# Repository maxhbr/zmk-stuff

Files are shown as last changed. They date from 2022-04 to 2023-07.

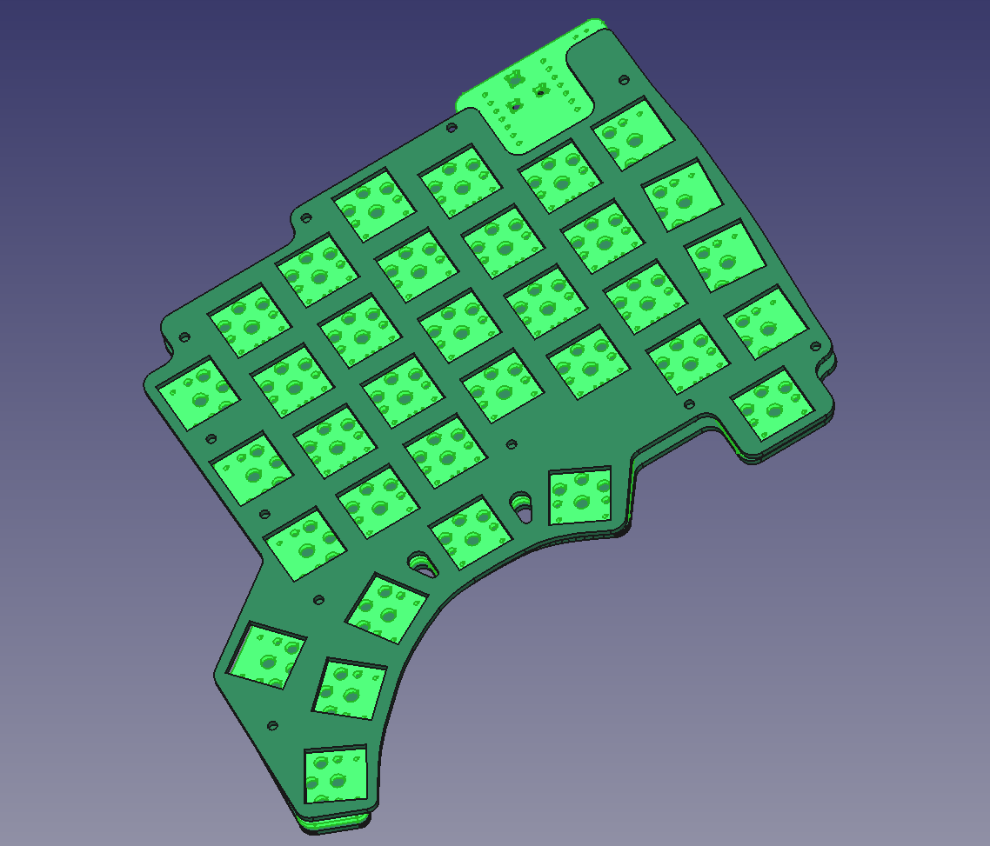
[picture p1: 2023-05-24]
mykeeb/rev7/mykeeb_v7a3/mykeeb_v7a3.png

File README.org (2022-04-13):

* zmk-stuff

** Keyboards
*** REDOX
my current daily driver
*** Kyria
Not sufficient amount of keys, not OSS
*** NYX
I am not happy with the thumb cluster, maybe it is good for gaming.
*** planned / parts exist / untested
**** ErgoDash
**** CRKBD

** Cases:
the cases are found in https://github.com/maxhbr/things/tree/main/keyboards

* TODOs:
** TODO clarify license situation
** TODO bulid configurations only on change?
** TODO design the perfect keyboard

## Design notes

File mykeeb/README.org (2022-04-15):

* mykeeb
** Why not an existing keeb
- [[https://github.com/mattdibi/redox-keyboard][REDOX]]
  - is very close
    - no HotSwap in the open source variant
- [[https://github.com/tadfisher/nyx-kb/][NYX]]
  - not happy with the thumb cluster
- Kyria
  - not OSS
  - to less keys
- [[https://github.com/omkbd/ErgoDash][ErgoDash]]
  - similar to REDOX
  - thumb cluster is forced to use one 2U
- [[https://github.com/jpconstantineau/ErgoTravel][ErgoTravel]]
- Zordiak is not OSS
- [[https://github.com/Pekaso/fortitude60][fortitude60]]
  - MCU is *Beetle USB 32u4* -> not supported by ZMK
- [[https://github.com/KarlK90/yaemk-split-kb][YAEMK]]
  - not supported by ZMK
- [[https://github.com/vlkv/avalanche][The Avalanche keyboard]]
  - tbd.

Other interesting Keyboards are Lily58, Lotus58, Sofle,

** Goals
- it *must* be fully OSS
  - especially also PCB and case
- it *must* support ZMK
  - it *could* have QMK support
- it *must* support 3D printed case and switch plate
  - it *should* have tenting support
- it *should* be split
- it *must* have columnar staggered layout
  - similar to Kyria or REDOX
    - Kyria aggressiveness is great!
- it *should* have _a lot_ of keys:
  - got used to 35 keys per side. Maybe 30 could also be sufficient.
  - it *must* have a thumb cluster
    - maybe a combination of REDOX-style and NYX-style
  - it *must* have 6 cols
    - it *should* have 7 cols, i.e. an additional center column
  - it *should* have a Number row
  - it *could* have arrow keys
  - it *does not need* to have encoder support
- it *could* have 1.5u keys for parts of the thumb cluster
- it *should* have MX style switches
  - it *could* also have Choc compatibility
    - maybe specifically for the thumb cluster?
- it *should* have HotSwap
  - preferred via Kailh sockets
- MCU *should* be mounted visible, and not on the back side
  - MCU *could* have two sockets to choose orientation per side
    - I like them chip side up
  - maybe similar to NYX, Kyria or crkbd
  - MCU *should* use a standard interconnect like Pro Micro
- it *should* have PCB support for a switch and battery connections
- it *could* expose i2c for trackball support
- it *could* have RGB-LED for feedback regarding activated layers or modifier
  - could also be done via display
  - could also be done via the trackpoint led
  - it *does not need* any further LED stuff

** How to start?
- base on something
  - REDOX
    - no HotSwap
  - ErgoDash
    - one less thumb key
  - NYX
    - has MX+Chock footprints, but does not fir 5pin MX
    - uses Horizon EDA
- from scratch
  - https://github.com/ruiqimao/keyboard-pcb-guide
  - which MCU
    - nRF52840
      - Nice!Nano
        - can easily do >=42 switches per side (41 on reviung41), using 6+7 GPIO pins
      - nRF52830 Dongle
        - 15 GPIOs
        - no LiPo support
      - Seeed XIAO BLE
        - has 11 GPIO pins
          - max 30=5*6 switches?
          - hummingbird has 30 switches
    - esp32

* Links:
- https://github.com/diimdeep/awesome-split-keyboards

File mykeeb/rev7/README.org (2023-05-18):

#+title: Readme

* Building a Redox Style Split with xiaos + Shift Registers

similar to https://github.com/maxhbr/redox-meets-dao-choc-ble, but with a different set of electronics.

*The shift registers are dropped for now, to iterate faster*

** The Idea:
*** Take the electronics from revxlp / uninarf
- Maybe with potential for (partial) JLC PCBA assembly
- using the xiao footprint from the TOTEM
*** Take the Rough layout from Redox
*** Adopt to the pinky stagger from the Kyria

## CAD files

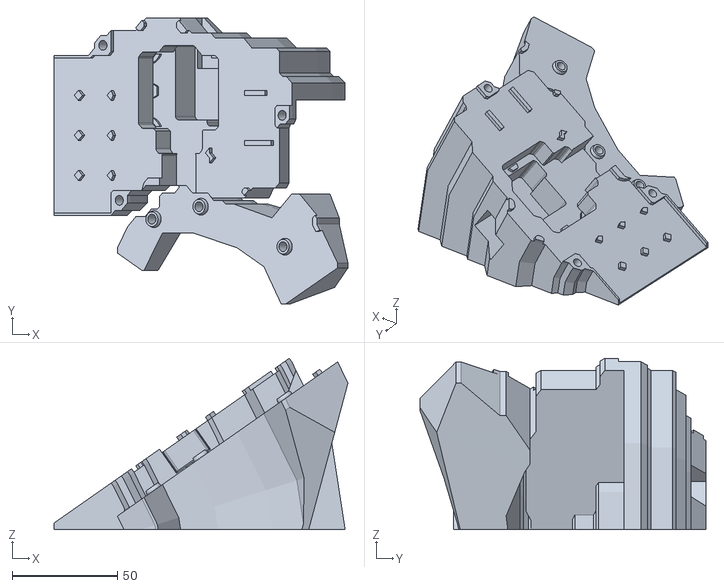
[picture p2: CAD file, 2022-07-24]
mykeeb/rev4c/case/mykeeb-wedge.stl
140.0 x 136.3 x 81.6

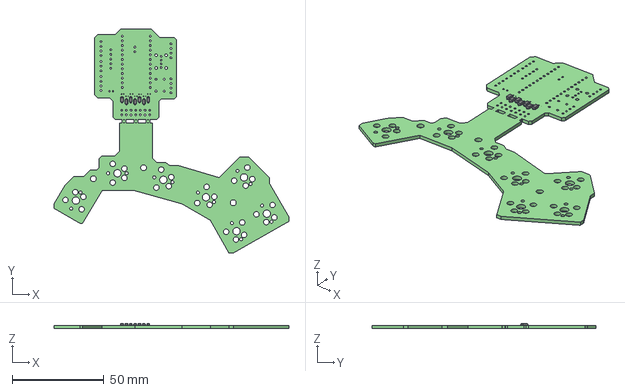
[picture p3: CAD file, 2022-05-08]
mykeeb/rev4c/mykeeb-adapter/mykeeb-adapter.step
128.0 x 122.0 x 2.75 mm
mykeeb-adapter PCB

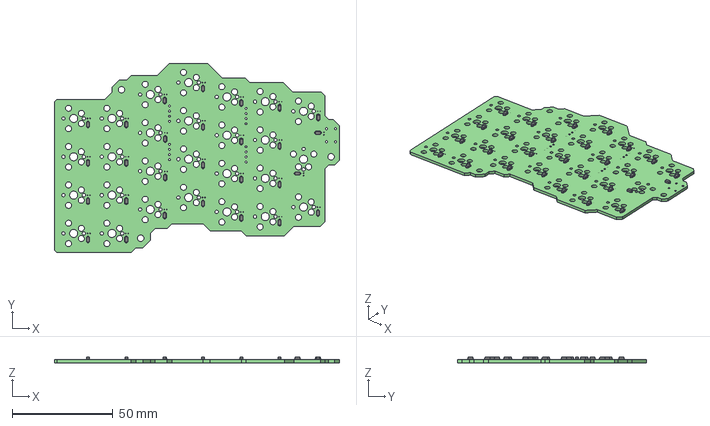
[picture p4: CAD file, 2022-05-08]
mykeeb/rev4c/mykeeb/mykeeb.step
141.7 x 94.1 x 2.75 mm
mykeeb PCB

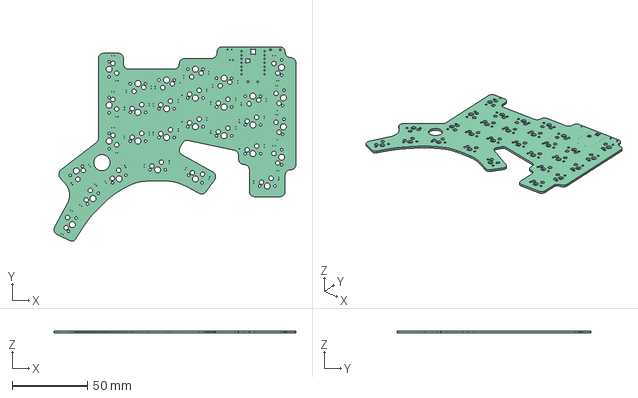
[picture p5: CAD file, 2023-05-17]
mykeeb/rev7/mykeeb_v7a2/mykeeb_v7a2_base/mykeep_v7a2_2023-05-16.FCStd
160.4 x 128.9 x 1.60 mm

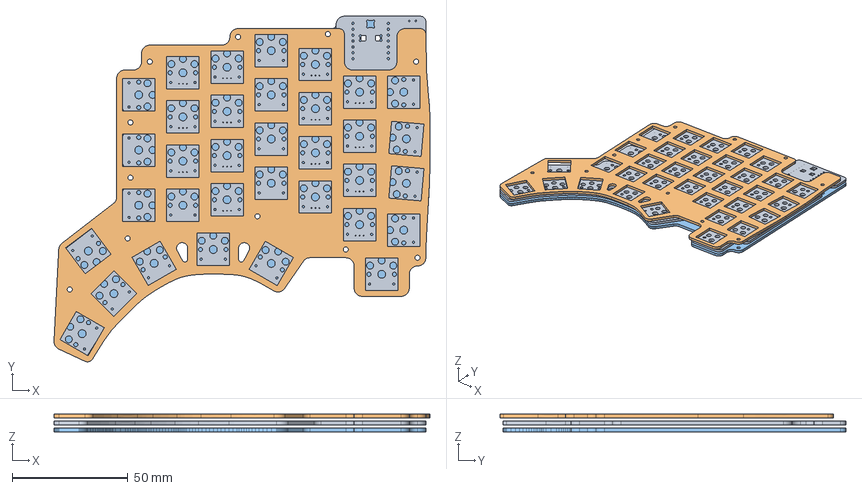
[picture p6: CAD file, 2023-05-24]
mykeeb/rev7/mykeeb_v7a3/mykeeb_v7a3.FCStd
162.2 x 149.1 x 7.60 mm
Pcb_73e4
Pcb_1d9e
Pcb_ed69

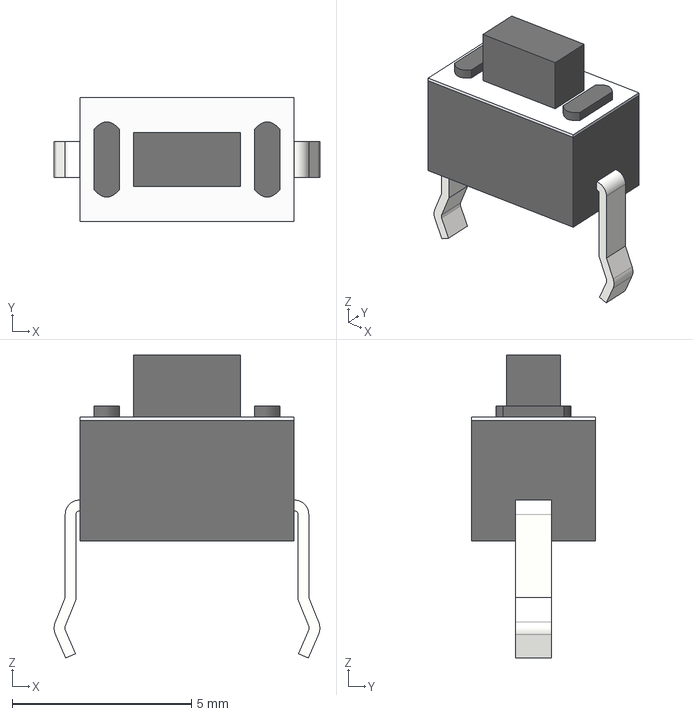
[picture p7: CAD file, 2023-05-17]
mykeeb/rev7/mykeeb_v7a5/pretty/3d_shapes/tact-switch.step
7.42 x 3.46 x 8.46 mm

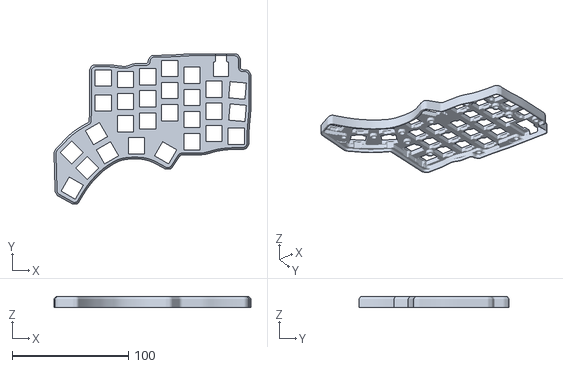
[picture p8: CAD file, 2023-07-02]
mykeeb/rev7/mykeeb_v7a5/stls/mykeeb_v7a5.no-lipo_case.right.stl
169.5 x 129.2 x 9.30

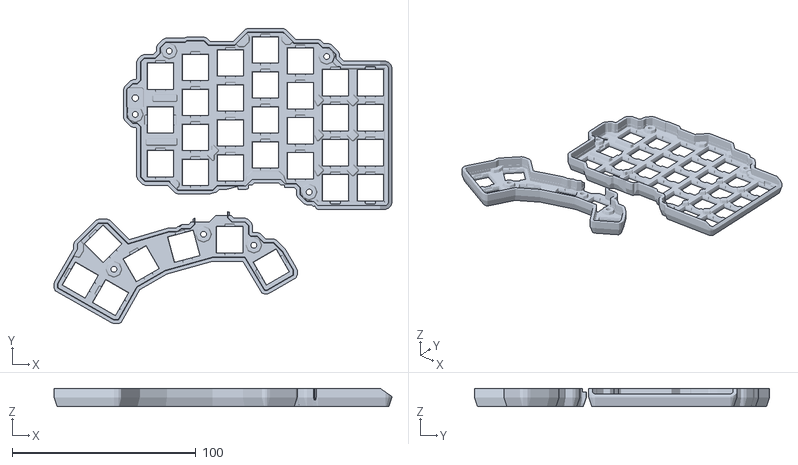
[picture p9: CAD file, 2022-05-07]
mykeeb/rev4c/case/mykeeb-lids.stl
184.0 x 160.8 x 10.0

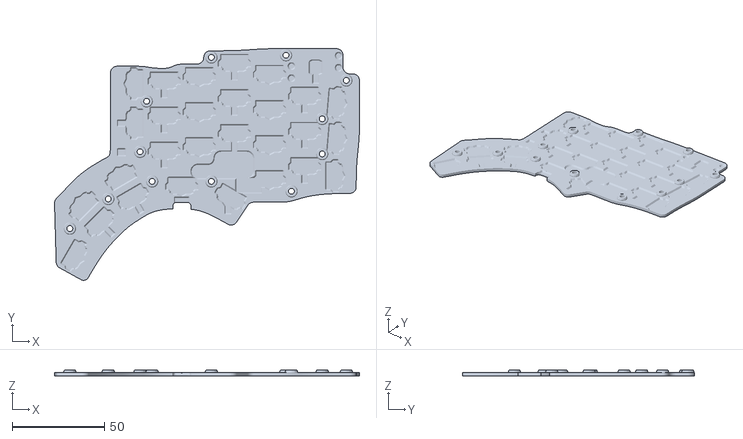
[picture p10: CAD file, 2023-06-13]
mykeeb/rev7/mykeeb_v7a5/stls/mykeeb_v7a5.base.right.stl
165.5 x 125.7 x 3.50

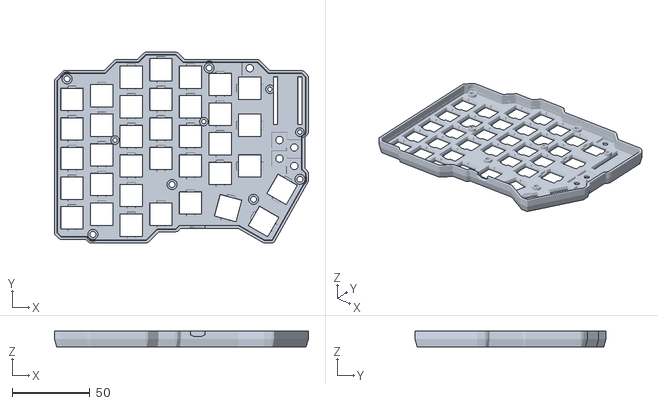
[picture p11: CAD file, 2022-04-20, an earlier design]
mykeeb/rev1/case/mykeeb.stl
163.3 x 123.0 x 10.0

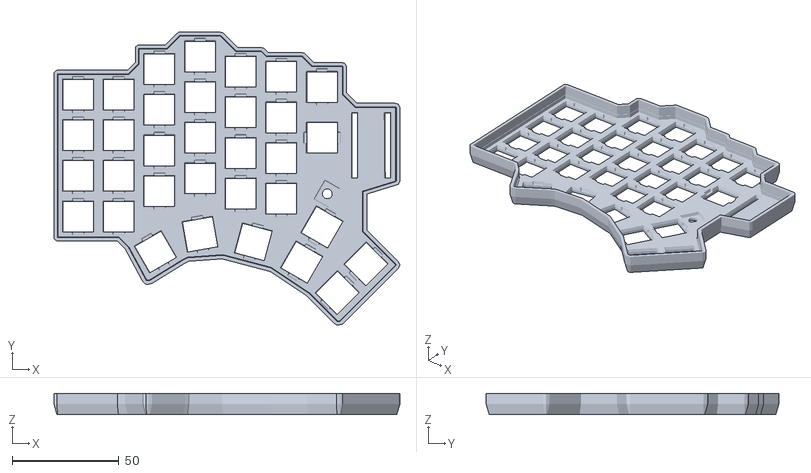
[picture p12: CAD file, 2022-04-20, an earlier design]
mykeeb/rev3/case/mykeeb.stl
162.2 x 137.2 x 10.0

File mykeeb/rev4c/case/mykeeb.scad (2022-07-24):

task=""; // ["","lids","wedge"]

angle=35;
lowerDrop=[0,0,-1.6-11];
lowerOffset=[-0.0005,-43.357,0];


// ############################################################################
// ## lib #####################################################################
// ############################################################################

module limitCube() {
    translate([0,0,-2])
        rotate([0,angle,0])
        translate([-20,-50,0])
        cube([200,150,100]);
}

module tent() {
    t=[-10,0,0];
    a=-35;
    translate(-t)
        rotate([0,a,0])
        translate(t)
        children();
}

module edge(h=3, top=true) {
    linear_extrude(height = h, convexity = 10)
        if (top) {
            import (file = "../mykeeb/mykeeb-Edge_Cuts.svg");
        } else {
            translate(lowerOffset)
                import (file = "../mykeeb-adapter/mykeeb-adapter-Edge_Cuts.svg");
        };
}

module screwHoles(h=10, top=true) {
    minkowski() {
        intersection() {
            linear_extrude(height = h, convexity = 10)
                if (top) {
                    import (file = "../mykeeb/mykeeb-Nutzer_1.svg");
                } else {
                    translate(lowerOffset)
                        import (file = "../mykeeb-adapter/mykeeb-adapter-Nutzer_1.svg");
                }
            edge(h=h,top=top);
        }
        children();
    }
}

module keyCutout(top=true) {
    translate([0,0,-5]) {
        minkowski() {
            intersection() {
                union() {
                    linear_extrude(height = 8.5, convexity = 10)
                        if (top) {
                            import (file = "../mykeeb/mykeeb-Nutzer_2.svg");
                            import (file = "../mykeeb/mykeeb-Nutzer_3.svg");
                        } else {
                            translate(lowerOffset) {
                                import (file = "../mykeeb-adapter/mykeeb-adapter-Nutzer_2.svg");
                                import (file = "../mykeeb-adapter/mykeeb-adapter-Nutzer_3.svg");
                            }
                        };
                }
                edge(h=8.5,top=top);
            }
            if (top) {
                intersection() {
                    linear_extrude(height = 9.2, convexity = 10)
                        import (file = "../mykeeb/mykeeb-Nutzer_5.svg");
                    edge(h=9.2,top=true);
                }
            }
            translate([0,0,-1.5]) cylinder(d1=1,d2=0,h=1.5,$fn=8);
        }
        intersection() {
            linear_extrude(height = 10, convexity = 10)
                if (top) {
                    import (file = "../mykeeb/mykeeb-Nutzer_2.svg");
                } else {
                    translate(lowerOffset)
                        import (file = "../mykeeb-adapter/mykeeb-adapter-Nutzer_2.svg");
                };
            edge(h=10, top=top);
        }
    }
}

// ############################################################################
// ## bottom ##################################################################
// ############################################################################

module bottomBoundary() {
    rotate([0,angle,0])
        linear_extrude(height = 100, convexity = 10)
        projection(cut = false)
        rotate([0,-angle,0]) {
            edge(top=true);
            edge(top=false);
        }
}
module bottom() {
    color("green")
        render(convexity = 2)
        difference() {
            intersection() {
                union() {
                    difference() {
                        translate([0,0,-1.6-2]) {
                            rotate([-90,0,0])
                                rotate_extrude(angle=angle, convexity=10)
                                import (file = "../mykeeb/mykeeb-Edge_Cuts.svg");
                            linear_extrude(height = 2, convexity = 10)
                                import (file = "../mykeeb/mykeeb-Nutzer_4.svg");
                            screwHoles(h=0.5, top=true)
                                cylinder(d1=5, d2=4, h=1.5, $fn=20);
                        }
                        minkowski() {
                            translate(lowerDrop + [0,0,-3])
                                edge(h=40, top=false);
                            cylinder(d=2, h=1, $fn=8);
                        }
                        screwHoles(h=0.5, top=true)
                            translate([0,0,-8])
                            cylinder(d1=1, h=1.5+8, $fn=20);
                        translate([67,0,-60]) rotate([0,55,0]) cube([100,55,100]);
                    }
                    translate(lowerDrop) {
                        difference() {
                            translate([0,0,-1.6-2]) {
                                rotate([-90,0,0])
                                    rotate_extrude(angle=angle, convexity=10) 
                                    translate(lowerOffset)
                                    import (file = "../mykeeb-adapter/mykeeb-adapter-Edge_Cuts.svg");
                                linear_extrude(height = 2, convexity = 10)
                                    translate(lowerOffset)
                                    import (file = "../mykeeb-adapter/mykeeb-adapter-Nutzer_4.svg");
                                screwHoles(h=0.5, top=false)
                                    cylinder(d1=5, d2=4, h=1.5, $fn=20);
                            }
                            screwHoles(h=0.5, top=false)
                                translate([0,0,-8])
                                cylinder(d1=1, h=1.5+8, $fn=20);
                            translate([65,-62,-100])
                                rotate([20,0,0])
                                cube([100,50,100]);
                            translate([80,-38,-80])
                                rotate([0,50,0])
                                cube([100,50,120]);
                        }
                    }
                }
                limitCube();
                rotate([0,angle,0])
                    translate([5,-50,-50])
                    cube([200,150,150]);
            }
            minkowski() {
                translate([0,0,-16-16])
                    linear_extrude(height = 16, convexity = 10)
                    translate(lowerOffset)
                    import (file = "../mykeeb-adapter/mykeeb-adapter-Nutzer_7.svg");
                cylinder(d=2, h=1, $fn=8);
            }

            translate([67,70,-36])
                cube([20,50,15]);
        }
}

// ############################################################################
// ## top #####################################################################
// ############################################################################

module plate(top=true) {
    difference(){
        union() {
            translate([0,0,2])
                difference() {
                    edge(h=3,top=top);
                    screwHoles(top=top) cylinder(d=0.2,h=1, $fn=20);
                    screwHoles(top=top) translate([0,0,1]) cylinder(d=3,h=1,$fn=20);
                }
        }
        keyCutout(top=top);
        if (! top) {
            edge(h=10,top=true);
        }
    }
}

module shroud(top=true) {
    addH=5;
    difference() {
        minkowski() {
            difference() {
                translate([0,0,-addH])
                    edge(h=5,top=top);
                if (! top) {
                    translate([0,0,-addH])
                        edge(h=10,top=true);
                }
            }
            cylinder(d1=4.5,d2=1,h=addH);

        }
        keyCutout(top=top);
        difference() {
            translate([0,0,-addH])
                edge(h=5+addH,top=top);
            difference() {
                    minkowski() {
                        union() {
                            linear_extrude(height = 2, convexity = 10)
                                if (top) {
                                    import (file = "../mykeeb/mykeeb-Nutzer_4.svg");
                                } else {
                                    translate(lowerOffset)
                                        import (file = "../mykeeb-adapter/mykeeb-adapter-Nutzer_4.svg");
                                };
                            screwHoles(h=1,top=top)
                                cylinder(h=1, d=4, $fn=8);
                        }
                        cylinder(h=2, d1=0.7, d2=2, $fn=8);
                    }

                    screwHoles(top=top) cylinder(d=0.2,h=1, $fn=20);
            }
        }
        minkowski() {
            translate([0,0,-addH])
                edge(h=addH-1, top=top);
            cylinder(d=0.5, h=1, $fn=8);
        }
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

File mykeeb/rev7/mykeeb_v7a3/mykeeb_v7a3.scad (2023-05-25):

svgs= [ "./svg/mykeeb_v7a3-Edge_Cuts.svg"
      , "./svg/mykeeb_v7a3-User_1.svg"
      , "./svg/mykeeb_v7a3-User_2.svg"
      , "./svg/mykeeb_v7a3-User_3.svg"
      , "./svg/mykeeb_v7a3-User_4.svg"
      , "./svg/mykeeb_v7a3-User_5.svg"
      , "./svg/mykeeb_v7a3-User_6.svg"
      , "./svg/mykeeb_v7a3-User_7.svg"
      , "./svg/mykeeb_v7a3-User_8.svg"
      , "./svg/mykeeb_v7a3-User_9.svg"
      ];
module svg_to_solid(idx=0,h=10) {
    minkowski() {
        linear_extrude(height = h, convexity = 10)
            import (file = svgs[idx]);
        children();
    }
}

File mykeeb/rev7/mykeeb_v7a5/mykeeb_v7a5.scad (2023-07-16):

// include lipo
var_type="case"; // ["case", "base","big-lipo-base","wip","wip-both","wip-big-lipo-base","wip-cuts"]
// which side
var_right=false; // [true,false]
// wireless?
var_lipo=true; // [true,false]
// tent?
var_tent=false; // [true,false]

/* [hidden] */

// tent_angle?
var_tent_angle=40; // [40]

$fn= $preview ? 32 : 64;

bottom_height=2.7;
height_below_pcb = 0.7;

svgs = ["svgs/mykeeb_v7a5-Edge_Cuts.svg"       // 0
       ,"svgs/mykeeb_v7a5-plate-Edge_Cuts.svg" // 1
       ,"svgs/mykeeb_v7a5-base-Edge_Cuts.svg"  // 2
       ,"svgs/mykeeb_v7a5-pcb.svg"             // 3
       ,"svgs/mykeeb_v7a5-no-holes.svg"        // 4
       ,"svgs/mykeeb_v7a5-no-no-holes.svg"     // 5
       ,"svgs/mykeeb_v7a5-holes.svg"           // 6
       ,"svgs/mykeeb_v7a5-cutout.svg"          // 7
       ,"svgs/mykeeb_v7a5-User_Comments.svg"   // 8
       ,"svgs/mykeeb_v7a5-User_1.svg"          // 9
       ,"svgs/mykeeb_v7a5-User_2.svg"          // 10
       ,"svgs/mykeeb_v7a5-User_3.svg"          // 11
       ,"svgs/mykeeb_v7a5-User_4.svg"          // 12
       ,"svgs/mykeeb_v7a5-User_5.svg"          // 13
       ,"svgs/mykeeb_v7a5-User_6.svg"          // 14
       ,"svgs/mykeeb_v7a5-User_7.svg"          // 15
       ,"svgs/mykeeb_v7a5-User_8.svg"          // 16
       ,"svgs/mykeeb_v7a5-User_9.svg"          // 17
       ,"svgs/mykeeb_v7a5-base-pcb.svg"        // 18
       ];

zOffset = [0,0,0];
fcadOffset = [-1.70619,-1.72682,0];
offsets = [zOffset
          ,zOffset
          ,zOffset
          ,fcadOffset
          ,fcadOffset
          ,fcadOffset
          ,fcadOffset
          ,fcadOffset
          ,zOffset
          ,zOffset
          ,zOffset
          ,zOffset
          ,zOffset
          ,zOffset
          ,zOffset
          ,zOffset
          ,zOffset
          ,zOffset
          ,fcadOffset
          ];

module svg(idx=0,height=1.6) {
    render()
        difference() {
            intersection() {
                cube([175,150,height]);
                linear_extrude(height = height)
                    translate(offsets[idx])
                    import(file = svgs[idx],  dpi = 96);
            }
            cube([20,20,height]);
            translate([160,120,0])
                cube([20,20,height]);
        };
}

module pcb(height=1.6) {
    svg(idx=3,height=height);
}

module base_pcb(height=1.6) {
    svg(idx=18,height=height);
}

module under_pcb_space(height=1) {
    svg(idx=9,height=height);
}
module next_to_pcb_space(height=1) {
    svg(idx=15,height=height);
}
module over_pcb_space(height=3) {
    svg(idx=11,height=height);
}
module switch_cutout(height=5) {
    svg(idx=12,height=height);
}

module m3_screw_holes(height, add_r=0) {
    // holes have a diam of 3.2
    if (add_r == 0) {
        svg(idx=17,height=height);
    } else {
        minkowski() {
            svg(idx=17,height=height-0.1);
            cylinder(r=add_r,h=0.1,$fn=12);
        };
    }
}

module m3_inserts(height) {
    m3_screw_holes(height, add_r=0.4);
}

module m3_support(height) {
    m3_screw_holes(height, add_r=1.8);
}

module quater_inch_insert() {
    translate([0,0,-bottom_height]) cylinder(d=8, h=12.7);
}

module quater_inch_support(){
    difference() {
        translate([0,0,-bottom_height]) cylinder(d=8+2*3.3, h=12.7+1);
        quater_inch_insert();
    }
}

module battery_space(height) {
    svg(idx=14,height=height);
}

module wiggle(d=0.2) {
    render()
    for (t = [[d,d,0],[0,d,0],[-d,d,0]
             ,[d,0,0],[0,0,0],[-d,0,0]
             ,[d,-d,0],[0,-d,0],[-d,-d,0]]) {
        translate(t) render() children();
    }
}

module battery_switch_subtract(force = false) {
    if (var_lipo && ! var_tent || force) {
        minkowski() {
            union() {
                translate([103,37,-8])
                    cube([6,10,14],center=true, $fn=20);
                 hull() {
                    translate([103,37,-13])
                        cube([6,10,14],center=true, $fn=20);
                    translate([103,37,-14])
                        cube([10,14,6],center=true, $fn=20);
                }
            }
            sphere(2,$fn=20);
        }
    }
}

module actual_pcb() {
    color([0,1,0,0.4])
        translate([93.5,90.5,0])
        import("mykeeb_v7a5.stl", convexity=3);
}

module tent(angle=var_tent_angle) {
    dx=7.5;
    translate([dx,0,0])
        rotate([0,-angle,0])
        translate([-dx,0,0])
        children();
}


module maybe_tent(angle=var_tent_angle) {
    if (var_tent) {
        tent(angle=angle)
            children();
    } else {
        children();
    }
}

module tent_wedge(angle) {
    intersection() {
                tent(-angle)
                linear_extrude(height = 300)
                    tent(angle)
                    translate(offsets[18])
                    import(file = svgs[18],  dpi = 96);
        translate([0,0,-200])
        cube([200,300,200]);
    }
}

module top_outer_hull() {
    h_over_zero = 5 + 1.6;
    h_below_zero = bottom_height;
    mink=2;
    render()
        minkowski() {
            translate([0,0,-bottom_height + mink])
                base_pcb(height=5 + 1.6 + bottom_height - mink);
            translate([0,0,- mink])
                cylinder($fn = 6, h=mink, r1=mink, r2=0.3);
        }
}

module top_inner_subtract() {
    space_over_pcb = 1;
    color("red") {
        translate([0,0,1.6])
            switch_cutout();
        translate([0,0,-10]) {
            difference() {
                minkowski() {
                    union() {
                        if (var_lipo) {
                            intersection_for(t=[[0,0,0],[0,-2.5,0],[-3,-1.5,0]]) {
                                translate(t)
                                    battery_space(height = 3.5 + 1.6 + 10);
                            }
                        }
                        over_pcb_space(height = 3.5 + 1.6 + 10);
                    }
                    translate([0,0,-1]) cylinder($fn = 6, h=1, r1=0.3, r2=0.2);
                }
                m3_support(height = 3.5 + 1.6 + 10);
            }
            difference() {
                wiggle(d=0.4)
                    pcb(height = 1.6 + 10 + space_over_pcb);
                m3_support(height = 1.6 + 10 + space_over_pcb);
            }
            intersection () {
                m3_screw_holes(height=10, add_r=6);
                base_pcb(height = 10);
            }
            wiggle(d=0.3) base_pcb(height = 10-height_below_pcb);
            next_to_pcb_space(height = 10+1.6+1);
            under_pcb_space(height = 10);
        }

        battery_switch_subtract();
    }
}

module top() {
    difference() {
        top_outer_hull();
        top_inner_subtract();
        translate([0,0,-10])
            m3_inserts(16.3);
        if(var_tent) {
            thickness_of_feed = 2;
            tent(-var_tent_angle)
                translate([0,0,-50-thickness_of_feed])
                cube([500,150,50]);
        }
    }
}

module bottom_m3_studs() {
    mink_h=0.6;
    translate([0,0,-bottom_height]) {
        minkowski() {
            m3_screw_holes(bottom_height-mink_h, add_r=1.3);
            cylinder($fn = 6, h=mink_h, r1=mink_h/2, r2=0);
        }
    }
}

module bottom_outer_hull() {
    translate([0,0,-bottom_height])
        base_pcb(height = bottom_height - height_below_pcb);
    bottom_m3_studs();
}

module tent_bottom_outer_hull(angle = var_tent_angle, inner_cutoff=10, add_h=0,over_tent=0) {
    intersection() {
        union() {
            bottom_outer_hull();
            translate([0,0,-bottom_height])
            tent_wedge(angle+over_tent);
            if(over_tent != 0) {
                mink_h = 1;
                minkowski() {
                    translate([0,0,-40-bottom_height - mink_h + 0.15 ]) m3_screw_holes(40, add_r=1.9);
                    cylinder(r1=0.5, r2=0, h=mink_h);
                }
            }
        }
        tent(-angle)
            translate([inner_cutoff,0,-add_h])
            cube([300,300,300]);
        cylinder(r=200,400, center=true);
    }
}

module common_bottom_inner_subtract() {
    difference() {
        union() {
            mink_h = 0.5;
            minkowski() {
                translate([0,0,-2.25]) {
                    under_pcb_space(height = 2.5);
                    if (var_lipo && !  var_tent) {
                        battery_space(height = 2.5);
                    }
                }
                cylinder(r1=0, r2=mink_h * 0.75, h=mink_h, $fn=12);
            }
            minkowski() {
                translate([0,0,-height_below_pcb-0.3]) {
                    under_pcb_space(height = height_below_pcb);
                    if (var_lipo && !  var_tent) {
                        battery_space(height = height_below_pcb);
                    }
                }
                cylinder(r1=mink_h * 0.75, r2=mink_h * 0.75+0.3, h=0.3, $fn=12);
            }
        }
        bottom_m3_studs();
    }
}
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

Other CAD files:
mykeeb/rev7/mykeeb_v7a5/stls/mykeeb_v7a5.no-lipo_case.left.stl
mykeeb/rev7/mykeeb_v7a5/stls/mykeeb_v7a5.case.left.stl
mykeeb/rev7/mykeeb_v7a5/stls/mykeeb_v7a5.case.right.stl
mykeeb/rev7/mykeeb_v7a5/stls/mykeeb_v7a5.base.left.stl
mykeeb/rev4b/mykeeb-adapter/mykeeb-adapter.step
mykeeb/rev4b/mykeeb/mykeeb.step
mykeeb/rev1/case/mykeeb.scad
mykeeb/rev1/case/mykeeb-bottom.stl
mykeeb/rev2/case/mykeeb.scad
mykeeb/rev3/case/mykeeb.scad
mykeeb/rev4b/mykeeb-adapter/mykeeb-adapter.stl
mykeeb/rev4c/mykeeb-adapter/mykeeb-adapter.stl

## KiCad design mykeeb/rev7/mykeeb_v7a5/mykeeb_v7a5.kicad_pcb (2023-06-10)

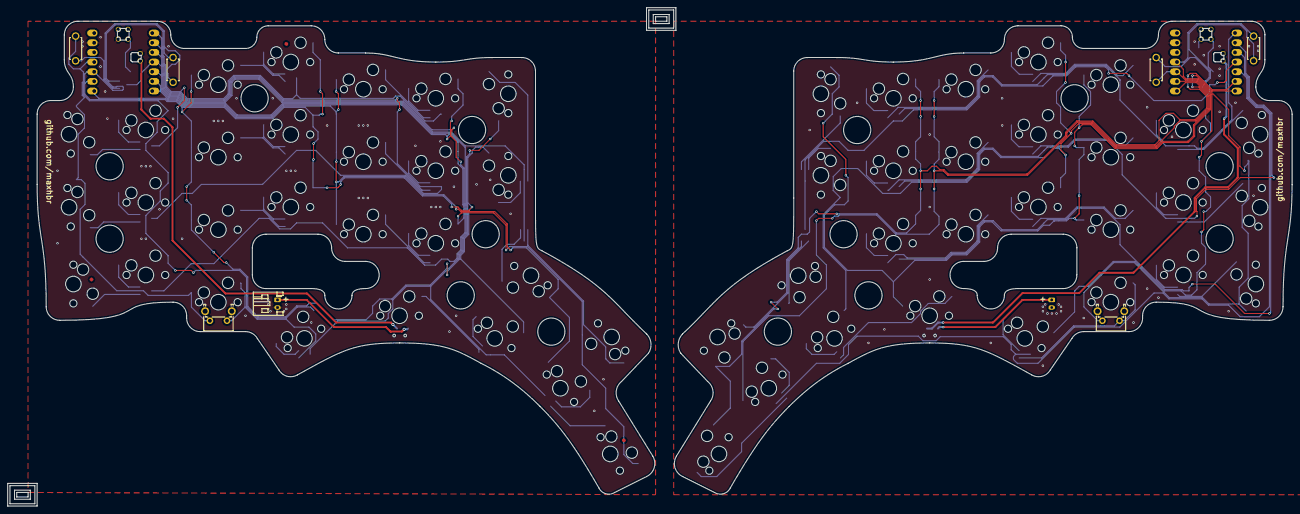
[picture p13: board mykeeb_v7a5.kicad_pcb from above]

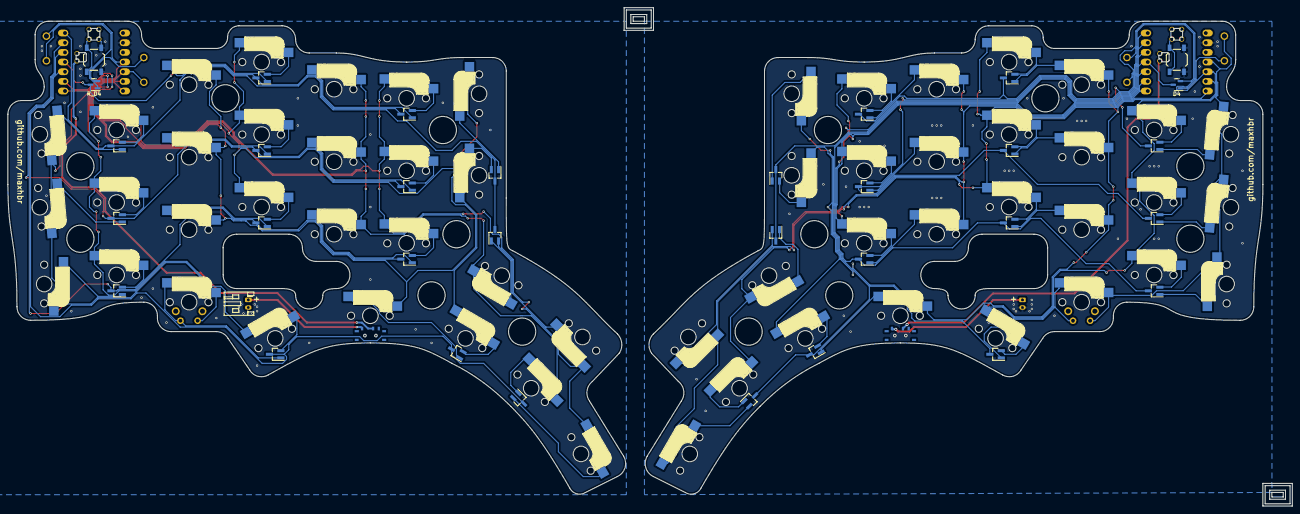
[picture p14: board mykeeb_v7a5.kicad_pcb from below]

Board: 2 copper layers, 337.5 x 131.0 mm, 103 parts (37 on the bottom side), 90 nets.

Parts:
BT1: Battery_Cell; JST_PH_S2B-PH-K_1x02_P2.00mm_Horizontal
D1, D2, D3, D4, D5, D6, D7, D8, D9, D10, D11, D12, D13, D14, D15: BAV70; SOT-23
FID1, FID2, FID3: Fiducial; Fiducial_1mm_Mask2mm
R_BT1: Battery_Cell; JST_PH_S2B-PH-K_1x02_P2.00mm_Horizontal
R_D1, R_D2, R_D3, R_D4, R_D5, R_D6, R_D7, R_D8, R_D9, R_D10, R_D11, R_D12, R_D13, R_D14, R_D15: BAV70; SOT-23
R_SA0, R_SA1, R_SA2, R_SA3, R_SA4, R_SA5: SW; CherryMX_Hotswap
R_SB0, R_SB1, R_SB2, R_SB3, R_SB4, R_SB5: SW; CherryMX_Hotswap
R_SC0, R_SC1, R_SC2, R_SC3, R_SC4, R_SC5: SW; CherryMX_Hotswap
R_SD0, R_SD1: SW_Push; PushSW
R_SD2: SW; CherryMX_Hotswap
R_SD3, R_SD4, R_SD5: SW; CherryMX_1.25U_Hotswap
R_SE0, R_SE3, R_SE4: SW; CherryMX_Hotswap
R_SE0_alt1: SW_Push; SW_Tactile_SPST_Angled_PTS645Vx39-2LFS
R_SE2: SW; CherryMX_1.25U_Hotswap
R_SW1: SW_Push; SW_SPST_TL3342
R_SW_bat1: SW_SPDT; switch-MSK-12C02-smd
R_U1: xiao-ble; xiao-ble-smd-cutout
SA0, SA1, SA2, SA3, SA4, SA5: SW; CherryMX_Hotswap
SB0, SB1, SB2, SB3, SB4, SB5: SW; CherryMX_Hotswap
SC0, SC1, SC2, SC3, SC4, SC5: SW; CherryMX_Hotswap
SD0, SD1: SW_Push; PushSW
SD2: SW; CherryMX_Hotswap
SD3, SD4, SD5: SW; CherryMX_1.25U_Hotswap
SE0, SE3, SE4: SW; CherryMX_Hotswap
SE0_alt1: SW_Push; SW_Tactile_SPST_Angled_PTS645Vx39-2LFS
SE2: SW; CherryMX_1.25U_Hotswap
SW1: SW_Push; SW_SPST_TL3342
SW_bat1: SW_SPDT; switch-MSK-12C02-smd
U1: xiao-ble; xiao-ble-smd-cutout
locked: SW; CherryMX_Hotswap
locked#2, locked#3, locked#4: SW; CherryMX_Hotswap

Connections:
BAT+: SW_bat1.2 (B), U1.19 (BAT)
GND: BT1.2 (-), SW1.2, U1.13 (GND), U1.18 (GND), U1.20 (GND)
unnamed: D1.1 (A1), SA0.2
unnamed: D1.2 (A2), SA1.1
unnamed: D2.1 (A1), SB0.2
unnamed: D2.2 (A2), SB1.1
unnamed: D3.1 (A1), SC0.2
unnamed: D3.2 (A2), SC1.1
unnamed: D4.1 (A1), SD0.2
unnamed: D4.2 (A2), SD1.1
unnamed: D5.1 (A1), SE0.2, SE0_alt1.1
unnamed: D5.2 (A2), locked#4.1
unnamed: D6.1 (A1), SA2.2
unnamed: D6.2 (A2), SA3.1
unnamed: D7.1 (A1), SB2.2
unnamed: D7.2 (A2), SB3.1
unnamed: D8.1 (A1), SC2.2
unnamed: D8.2 (A2), SC3.1
unnamed: D9.1 (A1), SD2.2
unnamed: D9.2 (A2), SD3.1
unnamed: D10.1 (A1), SE2.2
unnamed: D10.2 (A2), SE3.1
unnamed: D11.1 (A1), SA4.2
unnamed: D11.2 (A2), SA5.1
unnamed: D12.1 (A1), SB4.2
unnamed: D12.2 (A2), SB5.1
unnamed: D13.1 (A1), SC4.2
unnamed: D13.2 (A2), SC5.1
unnamed: D14.1 (A1), SD4.2
unnamed: D14.2 (A2), SD5.1
unnamed: D15.1 (A1), SE4.2
unnamed: D15.2 (A2), locked.1
unnamed: R_D1.1 (A1), R_SA0.2
unnamed: R_D1.2 (A2), R_SA1.1
unnamed: R_D2.1 (A1), R_SB0.2
unnamed: R_D2.2 (A2), R_SB1.1
unnamed: R_D3.1 (A1), R_SC0.2
unnamed: R_D3.2 (A2), R_SC1.1
unnamed: R_D4.1 (A1), R_SD0.2
unnamed: R_D4.2 (A2), R_SD1.1
unnamed: R_D5.1 (A1), R_SE0.2, R_SE0_alt1.1
unnamed: R_D5.2 (A2), locked#2.1
unnamed: R_D6.1 (A1), R_SA2.2
unnamed: R_D6.2 (A2), R_SA3.1
unnamed: R_D7.1 (A1), R_SB2.2
unnamed: R_D7.2 (A2), R_SB3.1
unnamed: R_D8.1 (A1), R_SC2.2
unnamed: R_D8.2 (A2), R_SC3.1
unnamed: R_D9.1 (A1), R_SD2.2
unnamed: R_D9.2 (A2), R_SD3.1
unnamed: R_D10.1 (A1), R_SE2.2
unnamed: R_D10.2 (A2), R_SE3.1
unnamed: R_D11.1 (A1), R_SA4.2
unnamed: R_D11.2 (A2), R_SA5.1
unnamed: R_D12.1 (A1), R_SB4.2
unnamed: R_D12.2 (A2), R_SB5.1
unnamed: R_D13.1 (A1), R_SC4.2
unnamed: R_D13.2 (A2), R_SC5.1
unnamed: R_D14.1 (A1), R_SD4.2
unnamed: R_D14.2 (A2), R_SD5.1
unnamed: R_D15.1 (A1), R_SE4.2
unnamed: R_D15.2 (A2), locked#3.1
RESET: SW1.1, U1.17 (RESET)
R_BAT+: R_SW_bat1.2 (B), R_U1.19 (BAT)
R_GND: R_SW1.2, R_U1.13 (GND), R_U1.18 (GND), R_U1.20 (GND)
R_RESET: R_SW1.1, R_U1.17 (RESET)
R_VBAT: R_BT1.1 (+), R_SW_bat1.1 (A)
R_col0: R_SA0.1, R_SB0.1, R_SC0.1, R_SD0.1, R_SE0.1, R_SE0_alt1.2, R_U1.11 (A6_MOSI/1.15)
R_col1: R_SA1.2, R_SB1.2, R_SC1.2, R_SD1.2, R_U1.10 (A5_MISO/1.14), locked#2.2
R_col2: R_SA2.1, R_SB2.1, R_SC2.1, R_SD2.1, R_SE2.1, R_U1.9 (A7_SCK/1.13)
R_col3: R_SA3.2, R_SB3.2, R_SC3.2, R_SD3.2, R_SE3.2, R_U1.8 (B9_RX/1.12)
R_col4: R_SA4.1, R_SB4.1, R_SC4.1, R_SD4.1, R_SE4.1, R_U1.7 (B8_TX/1.11)
R_col5: R_SA5.2, R_SB5.2, R_SC5.2, R_SD5.2, R_U1.6 (A9_SCL/0.05_H), locked#3.2
R_rowA: R_D1.3 (K), R_D6.3 (K), R_D11.3 (K), R_U1.1 (A2/0.02_H)
R_rowB: R_D2.3 (K), R_D7.3 (K), R_D12.3 (K), R_U1.2 (A4/0.03_H)
R_rowC: R_D3.3 (K), R_D8.3 (K), R_D13.3 (K), R_U1.3 (A10/0.28)
R_rowD: R_D4.3 (K), R_D9.3 (K), R_D14.3 (K), R_U1.4 (A11/0.29)
R_rowE: R_D5.3 (K), R_D10.3 (K), R_D15.3 (K), R_U1.5 (A8_SDA/0.04_H)
VBAT: BT1.1 (+), SW_bat1.1 (A)
col0: SA0.1, SB0.1, SC0.1, SD0.1, SE0.1, SE0_alt1.2, U1.11 (A6_MOSI/1.15)
col1: SA1.2, SB1.2, SC1.2, SD1.2, U1.10 (A5_MISO/1.14), locked#4.2
col2: SA2.1, SB2.1, SC2.1, SD2.1, SE2.1, U1.9 (A7_SCK/1.13)
col3: SA3.2, SB3.2, SC3.2, SD3.2, SE3.2, U1.8 (B9_RX/1.12)
col4: SA4.1, SB4.1, SC4.1, SD4.1, SE4.1, U1.7 (B8_TX/1.11)
col5: SA5.2, SB5.2, SC5.2, SD5.2, U1.6 (A9_SCL/0.05_H), locked.2
rowA: D1.3 (K), D6.3 (K), D11.3 (K), U1.1 (A2/0.02_H)
rowB: D2.3 (K), D7.3 (K), D12.3 (K), U1.2 (A4/0.03_H)
rowC: D3.3 (K), D8.3 (K), D13.3 (K), U1.3 (A10/0.28)
rowD: D4.3 (K), D9.3 (K), D14.3 (K), U1.4 (A11/0.29)
rowE: D5.3 (K), D10.3 (K), D15.3 (K), U1.5 (A8_SDA/0.04_H)

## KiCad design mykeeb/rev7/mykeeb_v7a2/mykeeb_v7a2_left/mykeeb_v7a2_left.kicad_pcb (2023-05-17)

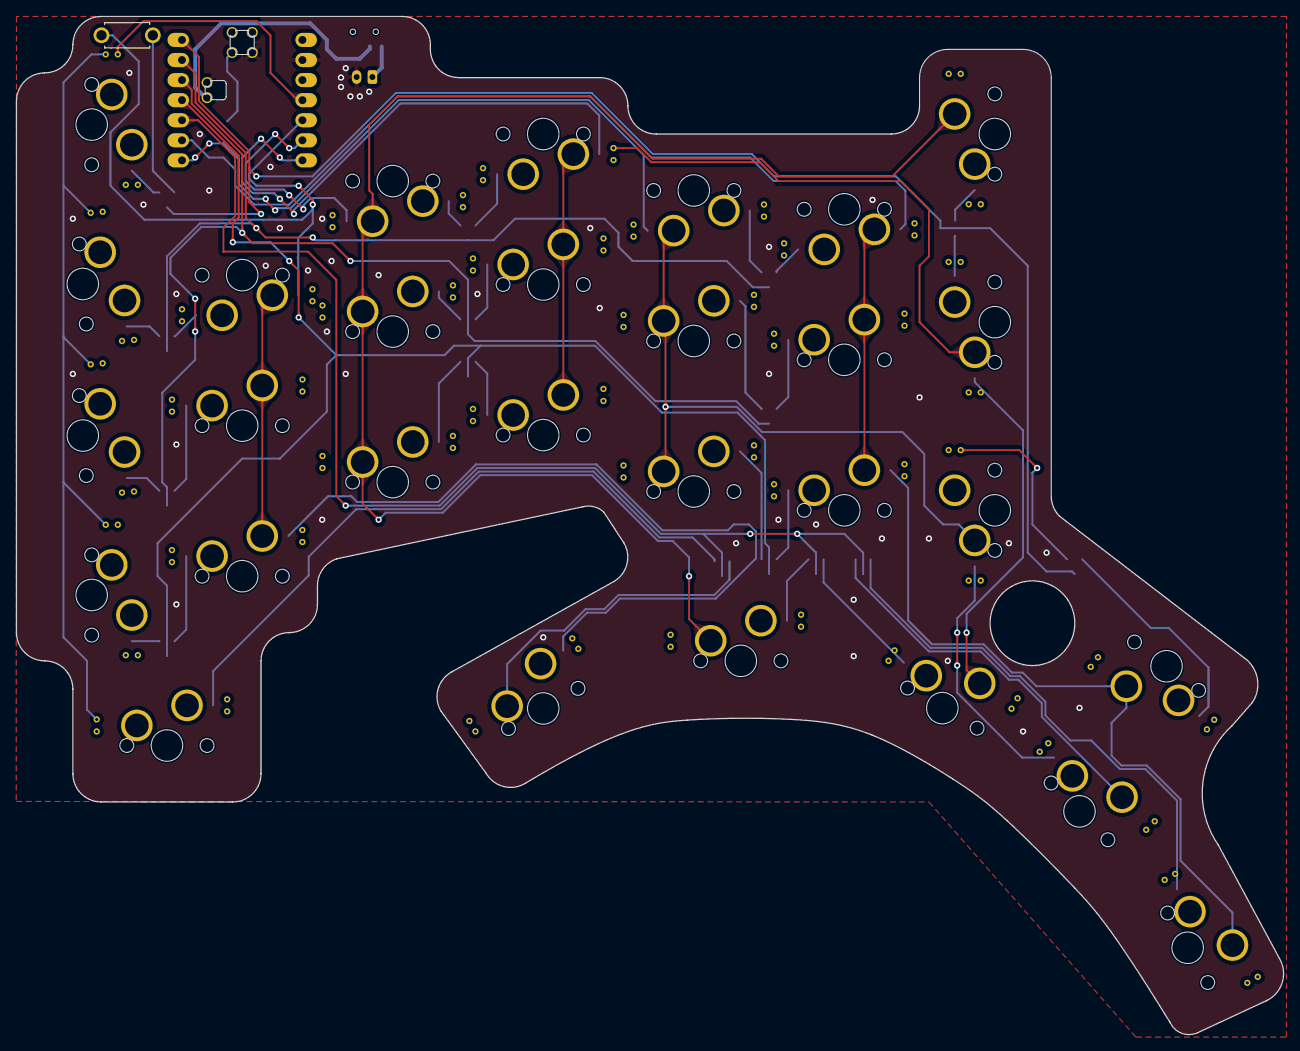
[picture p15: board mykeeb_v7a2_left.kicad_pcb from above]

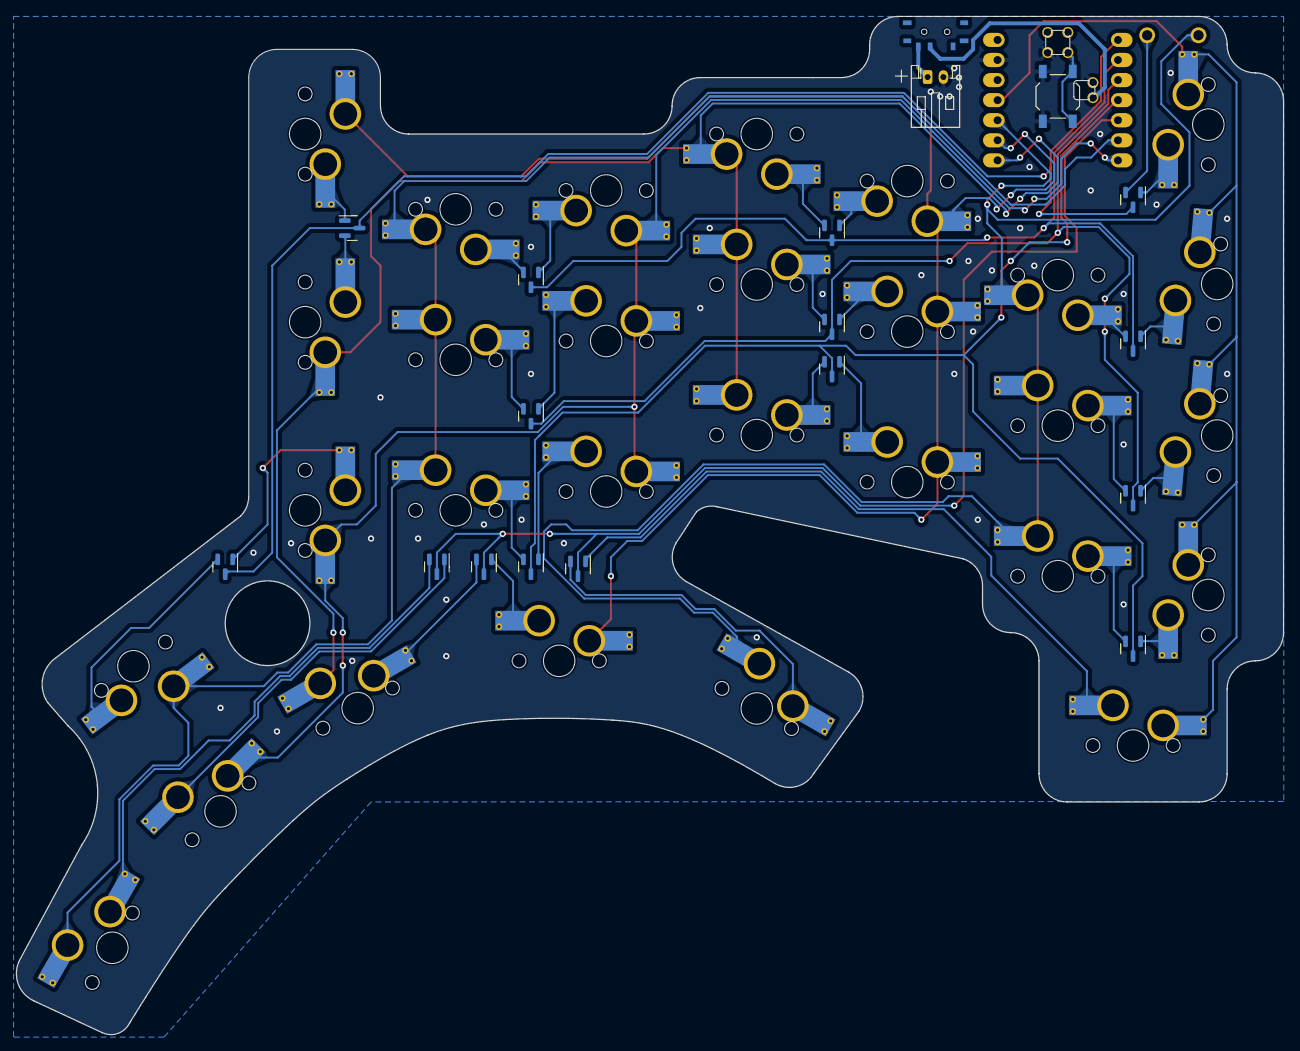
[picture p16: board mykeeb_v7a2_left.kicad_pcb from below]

Board: 2 copper layers, 160.4 x 128.9 mm, 49 parts (18 on the bottom side), 45 nets.

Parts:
L_BT1: Battery_Cell; JST_PH_S2B-PH-K_1x02_P2.00mm_Horizontal
L_D1, L_D2, L_D3, L_D4, L_D5, L_D6, L_D7, L_D8, L_D9, L_D10, L_D11, L_D12, L_D13, L_D14, L_D15: BAV70; SOT-23
L_S0, L_S2, L_S3, L_S4, L_S5, L_S10, L_S11, L_S12, L_S13, L_S14, L_S15, L_S20, L_S21, L_S22, L_S23, L_S24, L_S25, L_S30, L_S31, L_S32, L_S33, L_S34, L_S35, L_S40, L_S42, L_S43, L_S44: SW; MX-1U-Hotswap
L_S1: SW_Push; PushSW
L_SW_bat1: SW_SPDT; switch-MSK-12C02-smd
L_SW_reset1: SW_Push; SW_SPST_TL3342
L_U1: xiao-ble; xiao-ble-smd-cutout
locked: SW; MX-1U-Hotswap
locked#2: SW; MX-1U-Hotswap

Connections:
GND: L_BT1.2 (-), L_SW_reset1.2, L_U1.13 (GND), L_U1.18 (GND), L_U1.20 (GND)
L_BAT+: L_SW_bat1.2 (B), L_U1.19 (BAT)
L_COL0: L_S0.1, L_S10.1, L_S20.1, L_S30.1, L_S40.1, L_U1.11 (A6_MOSI/1.15)
L_COL1: L_S1.2, L_S11.1, L_S21.2, L_S31.2, L_U1.10 (A5_MISO/1.14), locked.2
L_COL2: L_S2.2, L_S12.2, L_S22.1, L_S32.1, L_S42.1, L_U1.9 (A7_SCK/1.13)
L_COL3: L_S3.1, L_S13.1, L_S23.2, L_S33.2, L_S43.2, L_U1.8 (B9_RX/1.12)
L_COL4: L_S4.1, L_S14.2, L_S24.1, L_S34.1, L_S44.1, L_U1.7 (B8_TX/1.11)
L_COL5: L_S5.2, L_S15.1, L_S25.2, L_S35.2, L_U1.6 (A9_SCL/0.05_H), locked#2.2
L_RESET: L_SW_reset1.1, L_U1.17 (RESET)
L_ROW0: L_D1.3 (K), L_D6.3 (K), L_D11.3 (K), L_U1.1 (A2/0.02_H)
L_ROW1: L_D2.3 (K), L_D7.3 (K), L_D12.3 (K), L_U1.2 (A4/0.03_H)
L_ROW2: L_D3.3 (K), L_D8.3 (K), L_D13.3 (K), L_U1.3 (A10/0.28)
L_ROW3: L_D4.3 (K), L_D9.3 (K), L_D14.3 (K), L_U1.4 (A11/0.29)
L_ROW4: L_D5.3 (K), L_D10.3 (K), L_D15.3 (K), L_U1.5 (A8_SDA/0.04_H)
L_VBAT: L_BT1.1 (+), L_SW_bat1.3 (C)
unnamed: L_D1.1 (A1), L_S0.2
unnamed: L_D1.2 (A2), L_S1.1
unnamed: L_D2.1 (A1), L_S10.2
unnamed: L_D2.2 (A2), L_S11.2
unnamed: L_D3.1 (A1), L_S20.2
unnamed: L_D3.2 (A2), L_S21.1
unnamed: L_D4.1 (A1), L_S30.2
unnamed: L_D4.2 (A2), L_S31.1
unnamed: L_D5.1 (A1), L_S40.2
unnamed: L_D5.2 (A2), locked.1
unnamed: L_D6.1 (A1), L_S2.1
unnamed: L_D6.2 (A2), L_S3.2
unnamed: L_D7.1 (A1), L_S12.1
unnamed: L_D7.2 (A2), L_S13.2
unnamed: L_D8.1 (A1), L_S22.2
unnamed: L_D8.2 (A2), L_S23.1
unnamed: L_D9.1 (A1), L_S32.2
unnamed: L_D9.2 (A2), L_S33.1
unnamed: L_D10.1 (A1), L_S42.2
unnamed: L_D10.2 (A2), L_S43.1
unnamed: L_D11.1 (A1), L_S4.2
unnamed: L_D11.2 (A2), L_S5.1
unnamed: L_D12.1 (A1), L_S14.1
unnamed: L_D12.2 (A2), L_S15.2
unnamed: L_D13.1 (A1), L_S24.2
unnamed: L_D13.2 (A2), L_S25.1
unnamed: L_D14.1 (A1), L_S34.2
unnamed: L_D14.2 (A2), L_S35.1
unnamed: L_D15.1 (A1), L_S44.2
unnamed: L_D15.2 (A2), locked#2.1

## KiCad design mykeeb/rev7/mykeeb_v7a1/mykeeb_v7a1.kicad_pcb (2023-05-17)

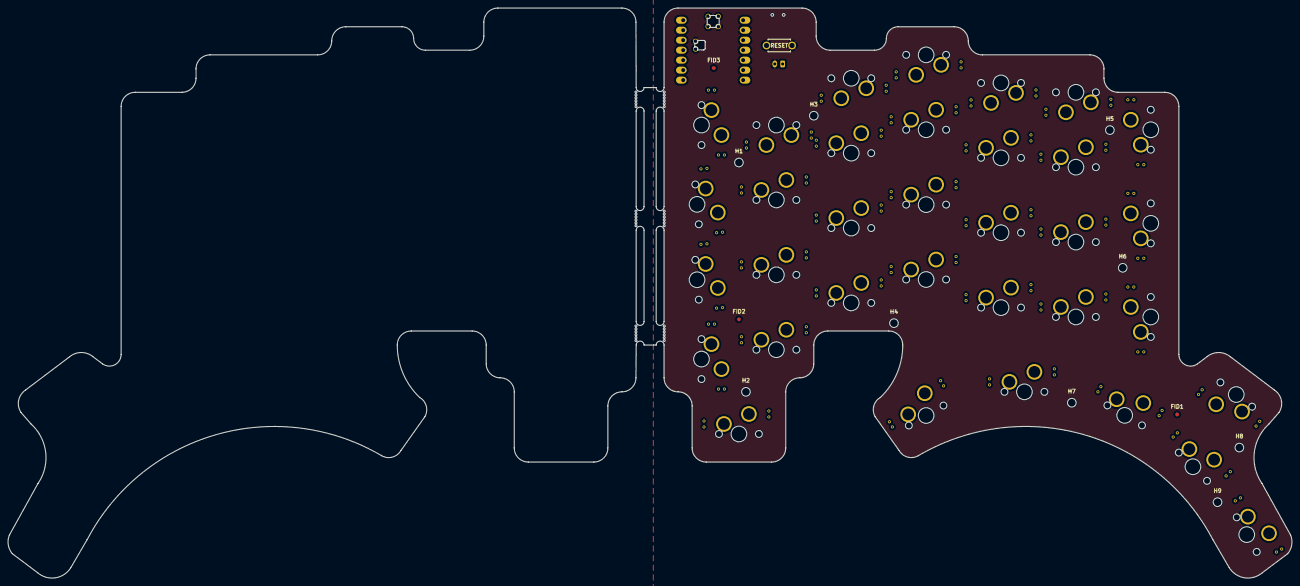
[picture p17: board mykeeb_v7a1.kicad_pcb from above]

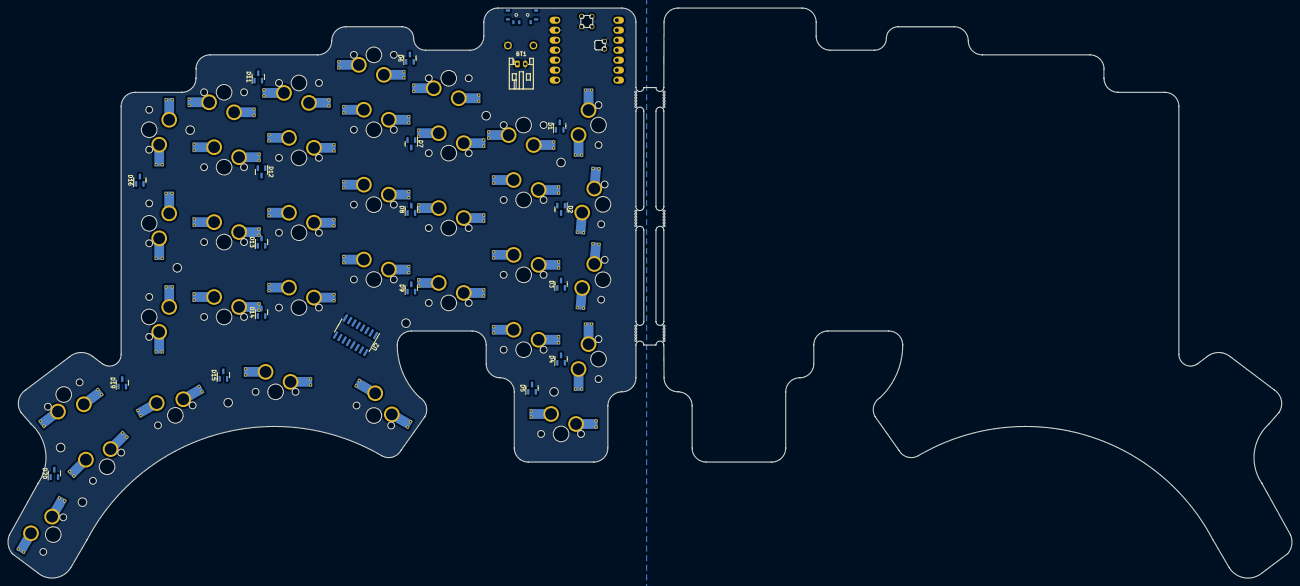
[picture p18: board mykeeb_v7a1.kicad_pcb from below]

Board: 2 copper layers, 326.6 x 145.0 mm, 68 parts (20 on the bottom side), 55 nets, no tracks yet.

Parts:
BT1: Battery_Cell; JST_PH_S2B-PH-K_1x02_P2.00mm_Horizontal
D1, D2, D3, D4, D5, D6, D7, D8, D9, D11, D12, D13, D14, D15, D16, D19, D20: BAV70; SOT-23
FID1, FID2, FID3: Fiducial; Fiducial_1mm_Mask2mm
H1, H2, H3, H4, H5, H6, H7, H8, H9: MountingHole; MountingHole_2.2mm_M2_DIN965
S0, S1, S2, S3, S4, S5, S6, S7, S10, S11, S12, S13, S14, S15, S20, S21, S22, S23, S24, S25, S30, S31, S32, S33, S34, S35, S36, S37, S40, S41, S42, S43, S44, S45: SW; MX-1U-Hotswap
SW_bat1: SW_SPDT; switch-MSK-12C02-smd
SW_reset1: SW_Push; ResetSW
U1: xiao-ble; xiao-ble-smd-cutout
U2: 74HC595; SOP-16_3.9x9.9mm_P1.27mm

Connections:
BAT+: SW_bat1.2 (B), U1.19 (BAT)
GND: BT1.2 (-), SW_reset1.2, U1.13 (GND), U1.18 (GND), U1.20 (GND), U2.8 (GND), U2.13 (~OE)
IO_CS: U1.8 (B9_RX/1.12), U2.12 (RCLK)
MOSI: U1.11 (A6_MOSI/1.15), U2.14 (SER)
unnamed: D1.1 (A1), S0.2
unnamed: D1.2 (A2), S1.1
unnamed: D2.1 (A1), S10.2
unnamed: D2.2 (A2), S11.1
unnamed: D3.1 (A1), S20.2
unnamed: D3.2 (A2), S21.1
unnamed: D4.1 (A1), S30.2
unnamed: D4.2 (A2), S31.1
unnamed: D5.1 (A1), S40.2
unnamed: D5.2 (A2), S41.1
unnamed: D6.1 (A1), S2.2
unnamed: D6.2 (A2), S3.1
unnamed: D7.1 (A1), S12.2
unnamed: D7.2 (A2), S13.1
unnamed: D8.1 (A1), S22.2
unnamed: D8.2 (A2), S23.1
unnamed: D9.1 (A1), S32.2
unnamed: D9.2 (A2), S33.1
unnamed: D11.1 (A1), S4.2
unnamed: D11.2 (A2), S5.1
unnamed: D12.1 (A1), S14.2
unnamed: D12.2 (A2), S15.1
unnamed: D13.1 (A1), S24.2
unnamed: D13.2 (A2), S25.1
unnamed: D14.1 (A1), S34.2
unnamed: D14.2 (A2), S35.1
unnamed: D15.1 (A1), S42.2
unnamed: D15.2 (A2), S43.1
unnamed: D16.1 (A1), S6.2
unnamed: D16.2 (A2), S7.1
unnamed: D19.1 (A1), S36.2
unnamed: D19.2 (A2), S37.1
unnamed: D20.1 (A1), S44.2
unnamed: D20.2 (A2), S45.1
RESET: SW_reset1.1, U1.17 (RESET)
SCK: U1.9 (A7_SCK/1.13), U2.11 (SRCLK)
VBAT: BT1.1 (+), SW_bat1.3 (C)
VCC: U1.12 (3V3), U2.10 (~SRCLR), U2.16 (VCC)
col0: S0.1, S10.1, S20.1, S30.1, S40.1
col1: S1.2, S11.2, S21.2, S31.2, S41.2
col2: S2.1, S12.1, S22.1, S32.1, S42.1
col3: S3.2, S13.2, S23.2, S33.2, S43.2
col4: S4.1, S14.1, S24.1, S34.1, S44.1
col5: S5.2, S15.2, S25.2, S35.2, S45.2
col6: S6.1, S36.1
col7: S7.2, S37.2
row0: D1.3 (K), D6.3 (K), D11.3 (K), D16.3 (K)
row1: D2.3 (K), D7.3 (K), D12.3 (K)
row2: D3.3 (K), D8.3 (K), D13.3 (K)
row3: D4.3 (K), D9.3 (K), D14.3 (K), D19.3 (K)
row4: D5.3 (K), D15.3 (K), D20.3 (K)

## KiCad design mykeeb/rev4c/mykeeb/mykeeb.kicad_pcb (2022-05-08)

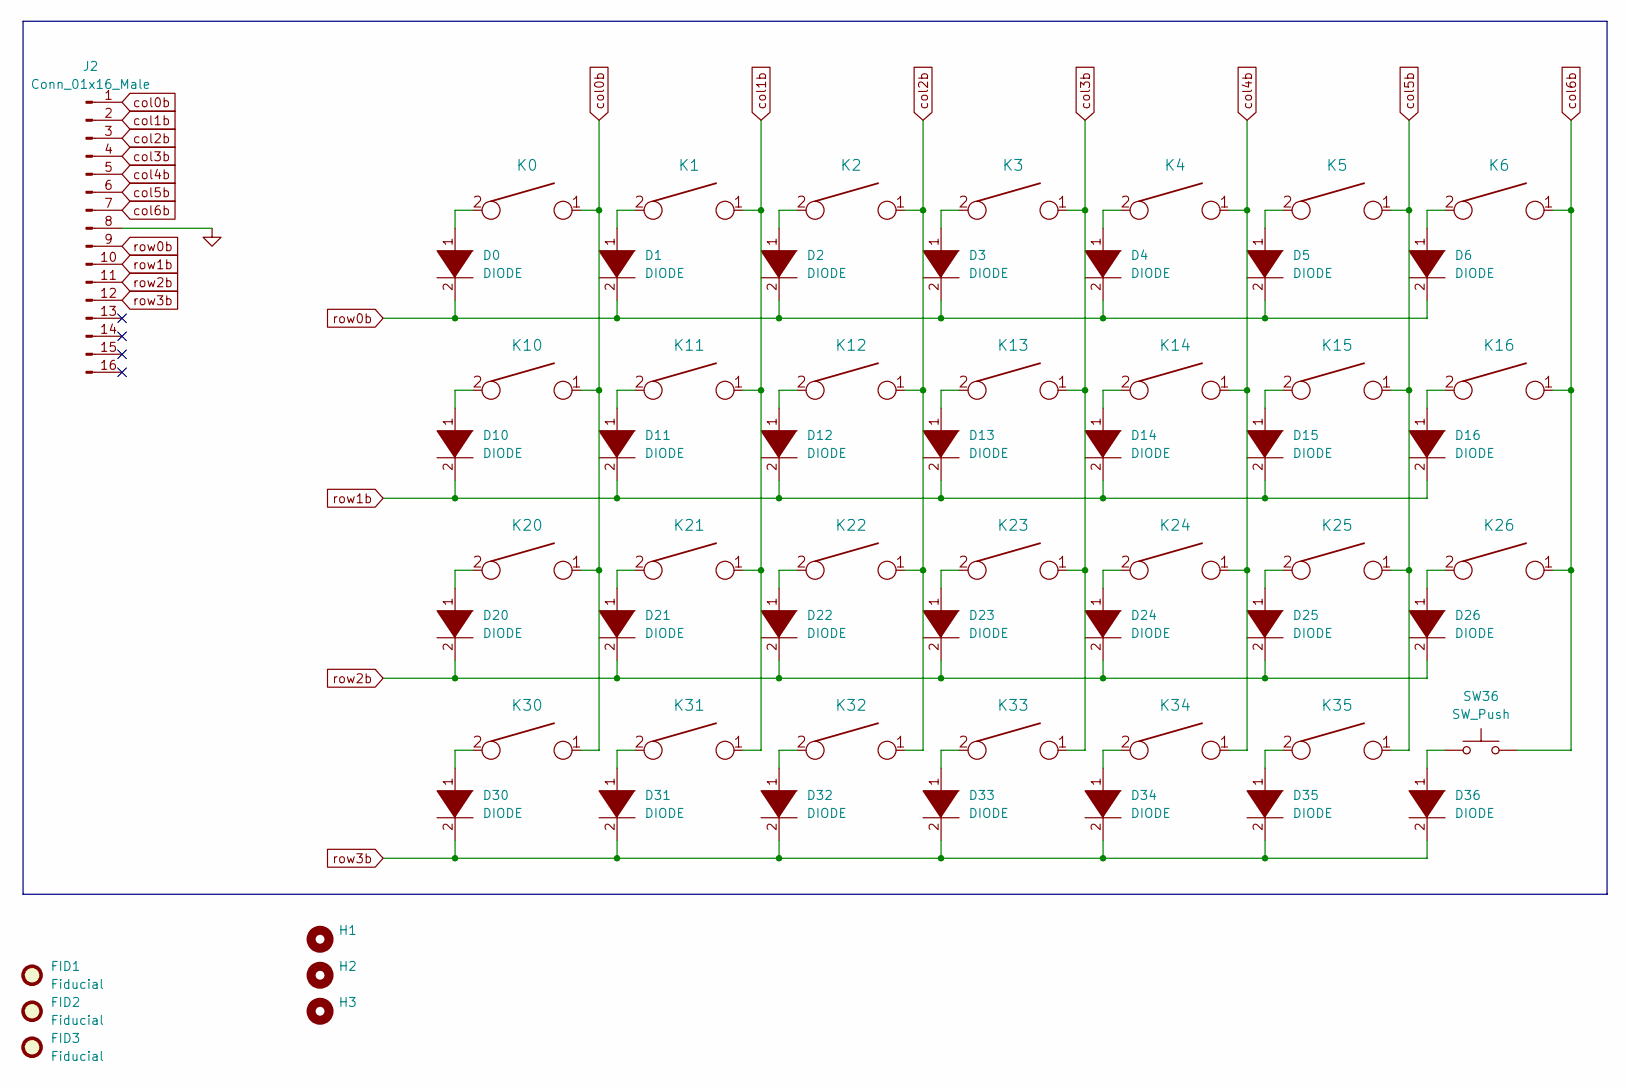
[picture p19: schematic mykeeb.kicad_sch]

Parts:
D0, D1, D2, D3, D4, D5, D6, D10, D11, D12, D13, D14, D15, D16, D20, D21, D22, D23, D24, D25, D26, D30, D31, D32, D33, D34, D35: DIODE; my_dual_D_SOD123F_v2
D36: DIODE; my_dual_D_SOD123F_v2b
FID1, FID2, FID3: Fiducial; Fiducial_1mm_Mask2mm
H1, H2, H3: (no value)
J2: Conn_01x16_Male; adapterBoard
K0, K1, K2, K3, K4, K5, K6, K10, K11, K12, K13, K14, K15, K20, K21, K22, K23, K24, K25, K26, K30, K31, K32, K33, K34, K35: KEYSW; Kailh_socket_MX_reversible_1u
K16: KEYSW; Kailh_socket_MX_reversible_1.5u
SW36: SW_Push; SW_PUSH_6mm_H7.3mm

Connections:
GND: J2.8
unnamed: D0.1 (K), K0.2
unnamed: D1.1 (K), K1.2
unnamed: D2.1 (K), K2.2
unnamed: D3.1 (K), K3.2
unnamed: D4.1 (K), K4.2
unnamed: D5.1 (K), K5.2
unnamed: D6.1 (K), K6.2
unnamed: D10.1 (K), K10.2
unnamed: D11.1 (K), K11.2
unnamed: D12.1 (K), K12.2
unnamed: D13.1 (K), K13.2
unnamed: D14.1 (K), K14.2
unnamed: D15.1 (K), K15.2
unnamed: D16.1 (K), K16.2
unnamed: D20.1 (K), K20.2
unnamed: D21.1 (K), K21.2
unnamed: D22.1 (K), K22.2
unnamed: D23.1 (K), K23.2
unnamed: D24.1 (K), K24.2
unnamed: D25.1 (K), K25.2
unnamed: D26.1 (K), K26.2
unnamed: D30.1 (K), K30.2
unnamed: D31.1 (K), K31.2
unnamed: D32.1 (K), K32.2
unnamed: D33.1 (K), K33.2
unnamed: D34.1 (K), K34.2
unnamed: D35.1 (K), K35.2
unnamed: D36.1 (K), SW36.1
col0b: J2.1, K0.1, K10.1, K20.1, K30.1
col1b: J2.2, K1.1, K11.1, K21.1, K31.1
col2b: J2.3, K2.1, K12.1, K22.1, K32.1
col3b: J2.4, K3.1, K13.1, K23.1, K33.1
col4b: J2.5, K4.1, K14.1, K24.1, K34.1
col5b: J2.6, K5.1, K15.1, K25.1, K35.1
col6b: J2.7, K6.1, K16.1, K26.1, SW36.2
row0b: D0.2 (A), D1.2 (A), D2.2 (A), D3.2 (A), D4.2 (A), D5.2 (A), D6.2 (A), J2.9
row1b: D10.2 (A), D11.2 (A), D12.2 (A), D13.2 (A), D14.2 (A), D15.2 (A), D16.2 (A), J2.10
row2b: D20.2 (A), D21.2 (A), D22.2 (A), D23.2 (A), D24.2 (A), D25.2 (A), D26.2 (A), J2.11
row3b: D30.2 (A), D31.2 (A), D32.2 (A), D33.2 (A), D34.2 (A), D35.2 (A), D36.2 (A), J2.12

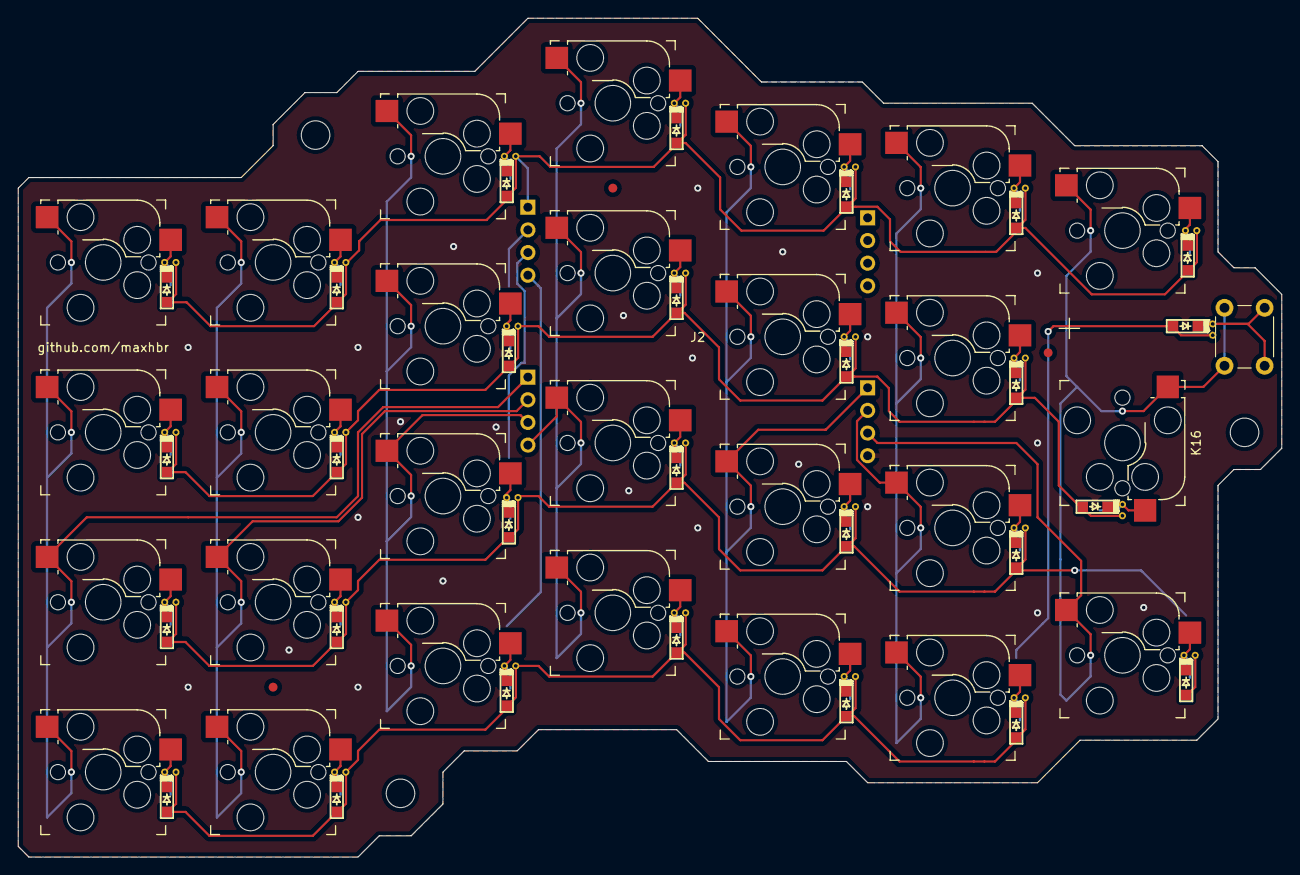
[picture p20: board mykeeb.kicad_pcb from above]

Board: 2 copper layers, 141.7 x 94.1 mm, 63 parts (0 on the bottom side), 39 nets.

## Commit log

2022-04-16 wip on mykeeb
    [mykeeb.kicad_pcb, mykeeb.kicad_sch]
2022-04-18 add v0.1 pcb
    [mykeeb.kicad_pcb, mykeeb.kicad_sch, mykeeb.scad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]
2022-04-20 order rev1
    [mykeeb-B_Cu.gbr, mykeeb-B_Mask.gbr, mykeeb-B_Paste.gbr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]
2022-04-20 move rev1 to subfolder
    [mykeeb-B_Cu.gbr, mykeeb-B_Mask.gbr, mykeeb-B_Paste.gbr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]
2022-04-20 add case for mykeeb v1
    [mykeeb-bottom.stl, mykeeb.kicad_pcb, mykeeb.scad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]
2022-04-20 work on rev2
    [mykeeb.kicad_pcb, mykeeb.kicad_sch, mykeeb.scad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]
2022-04-24 wip on rev3
    [mykeeb.kicad_pcb, mykeeb.kicad_sch, mykeeb.scad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]
2022-05-08 commit rev4c gerbers
    [mykeeb-adapter.kicad_pcb, mykeeb-adapter.kicad_sch, mykeeb-adapter.step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]
2022-07-24 make wedge smaller
    [mykeeb-wedge.stl, mykeeb.scad]
2022-08-24 commit rev5 (WIP)
    [mykeeb.kicad_pcb, mykeeb.kicad_sch]
2023-04-02 add two new boards
2023-05-08 init kicad project
    [mykeeb_v7a1.kicad_pcb, mykeeb_v7a1.kicad_sch]
2023-05-17 top and bottom plate
    [mykeeb_v7a2.kicad_sch, mykeeb_v7a2_base.kicad_pcb, mykeeb_v7a2_base.kicad_sch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]
2023-05-17 add gerber files for v7a2
    [mykeeb_v7a2.kicad_sch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]
2023-05-23 add choc v7a3
    [mykeeb_v7a3-B_Cu.gbl, mykeeb_v7a3-B_Mask.gbs, mykeeb_v7a3-B_Paste.gbp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]
2023-05-24 finalize v7a3 for now
    [mykeeb_v7a3.kicad_pcb, mykeeb_v7a3.kicad_sch]
2023-05-24 add plates
    [mykeeb_v7a3-base.kicad_pcb, mykeeb_v7a3-base.kicad_sch, mykeeb_v7a3-plate.kicad_pcb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]
2023-05-25 update gerbers, step 1
    [mykeeb_v7a3-B_Cu.gbl, mykeeb_v7a3-B_Mask.gbs, mykeeb_v7a3-B_Paste.gbp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]
2023-05-25 update gerbers for v7a3
    [mykeeb_v7a3-base-B_Cu.gbl, mykeeb_v7a3-base-B_Mask.gbs, mykeeb_v7a3-base-B_Paste.gbp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]
2023-05-29 start v7a4
    [mykeeb_v7a4.kicad_pcb, mykeeb_v7a4.kicad_sch, mykeeb_v7a4.sch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]
2023-06-08 work on v7a5
    [mykeeb_v7a5.kicad_pcb, mykeeb_v7a5.kicad_sch]
2023-06-10 openscad? -> yes!
    [mykeeb_v7a5-base.kicad_pcb, mykeeb_v7a5-plate.kicad_pcb, mykeeb_v7a5.kicad_pcb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]
2023-06-10 add case
    [mykeeb_v7a5.base.left.stl, mykeeb_v7a5.base.right.stl, mykeeb_v7a5.kicad_pcb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]
2023-06-11 work on case
    [mykeeb_v7a5.base.left.stl, mykeeb_v7a5.base.right.stl, mykeeb_v7a5.left.stl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]
2023-06-12 lipo switch
    [mykeeb_v7a5.scad]
2023-06-13 add gerbers
    [mykeeb_v7a5-B_Cu.gbl, mykeeb_v7a5-B_Mask.gbs, mykeeb_v7a5-B_Paste.gbp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]
2023-06-13 ordered v7a5
    [mykeeb_v7a5-B_Cu.gbl, mykeeb_v7a5-B_Mask.gbs, mykeeb_v7a5-B_Paste.gbp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]
2023-06-13 render 3d models
    [mykeeb_v7a5.base.left.stl, mykeeb_v7a5.base.right.stl, mykeeb_v7a5.left.stl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]
2023-06-15 update stls
    [mykeeb_v7a5.left.stl, mykeeb_v7a5.right.stl, mykeeb_v7a5.scad]
2023-06-16 support multiple tenting angles at once
    [mykeeb_v7a5.scad]
2023-06-17 work on tent case??
    [mykeeb_v7a5.left.stl, mykeeb_v7a5.right.stl, mykeeb_v7a5.scad]
2023-06-19 regenerate STLs
    [mykeeb_v7a5.left.stl, mykeeb_v7a5.right.stl]
2023-06-21 fix the small 'MCU on the wrong side' issue
    [mykeeb_v7a5-B_Cu.gbl, mykeeb_v7a5-B_Mask.gbs, mykeeb_v7a5-B_Paste.gbp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]
2023-06-22 yet another base?
    [mykeeb_v7a5.case.left.stl, mykeeb_v7a5.case.right.stl, mykeeb_v7a5.left.stl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]
2023-07-02 widen battery cutout
    [mykeeb_v7a5.scad]
2023-07-02 rebuild stls
    [mykeeb_v7a5.case.left.stl, mykeeb_v7a5.case.right.stl, mykeeb_v7a5.no-lipo_case.left.stl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]
2023-07-16 update pcb after messup
    [mykeeb_v7a5-B_Cu.gbl, mykeeb_v7a5-B_Mask.gbs, mykeeb_v7a5-B_Paste.gbp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]

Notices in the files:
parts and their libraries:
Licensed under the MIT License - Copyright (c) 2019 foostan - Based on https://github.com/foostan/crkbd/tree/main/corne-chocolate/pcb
